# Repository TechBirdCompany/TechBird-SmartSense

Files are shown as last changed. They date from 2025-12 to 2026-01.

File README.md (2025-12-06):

# Introduction
TechBird-SmartSense is an IoT device with a 4-channel 12-Bit ADC, to measure up to 4 temperatures. In addition it also provides an internal temperature sensore for ambiant temperatures.

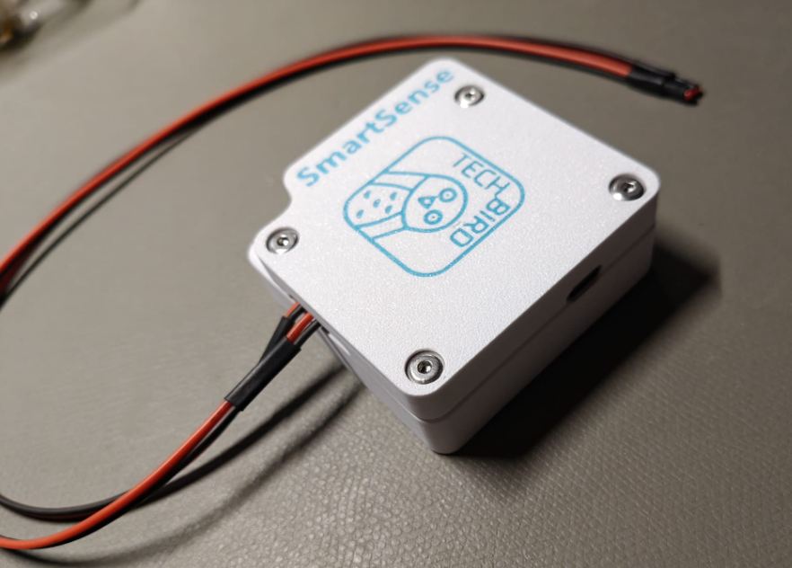
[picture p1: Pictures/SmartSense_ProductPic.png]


# Features
- ESP32-C6-MINI-1-N4: As module
- EEMB LP103454: 2000 mAh Lipo Battery
  - 7 days of uptime with 10 seconds time gab, and ringbuffer size of 60
- ADS1015IDGSR: 2 Differntiall or 4 Channel 12-Bit ADC
- FM24CL64B-GTR: 64 kB FRAM
- RV-3028-C7: Internal RTC
- TMP1075D: Internal Temperature Sensor
- USB Type-C for communication and charging
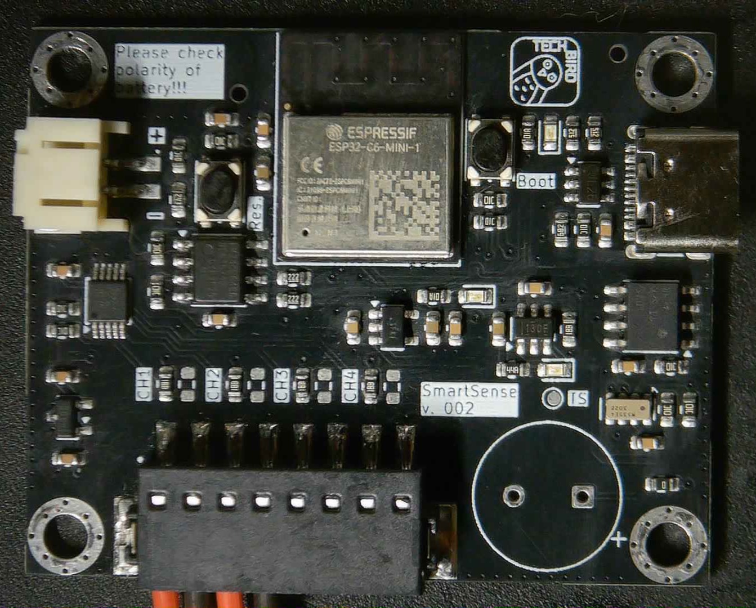
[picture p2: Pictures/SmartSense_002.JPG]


# Software
- Use at your own risk!
- Basic UI via USB (115200, 8, n, 1)
- Sending Data via MQTT
- Again... use at your own risk!
- Bugs are free to find, and free to fix.

# Known Bugs
## Hardware
- For some reasons, unknown to men, the LiPo Battery is necessary, to provide enough energy for initial W-LAN connection. Or maybe use a beefier USB power supply
- <span style="text-decoration:overline">WKUP</span> need to be routed to IO2
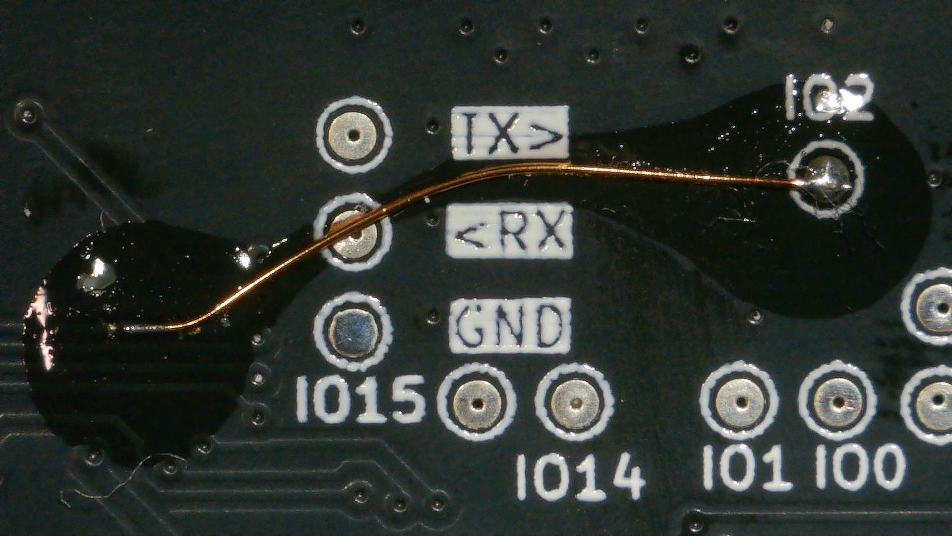
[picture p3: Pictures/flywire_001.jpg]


## Software
- When ringbuffer loops, one set of wrong data will be send

# Known Nuisances
- When in deep sleep, attaching USB connection won't reset the device and the lid need to be removed in order to get to the bootmenu
- Main connector is not made to be removed frequently, which makes charging pretty annoying

# Arduino IDE Setup
- The settings should look something like this:
  
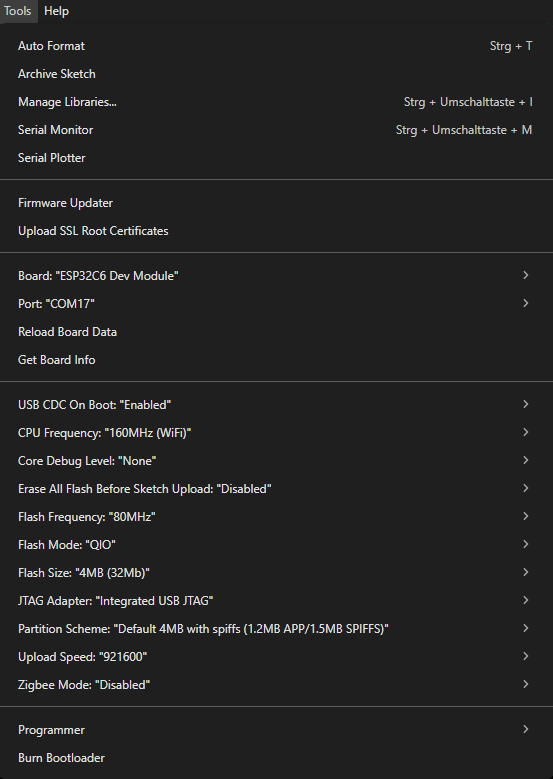
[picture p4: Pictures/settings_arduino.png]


- The following libraries shoulld be installed:
  - https://github.com/arduino-libraries/Arduino_JSON
  - https://github.com/arduino-libraries/NTPClient
  - https://github.com/adafruit/Adafruit_ADS1X15
  - https://github.com/hideakitai/DebugLog
  - https://github.com/RobTillaart/FRAM_I2C
  - https://github.com/256dpi/arduino-mqtt
  - https://github.com/constiko/RV-3028_C7-Arduino_Library
  - https://github.com/PatrickBaus/Arduino-TMP1075/tree/master
    - Needs to be installed manually

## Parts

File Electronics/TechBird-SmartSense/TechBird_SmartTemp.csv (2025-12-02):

Reference | Qty | Value | Tolerance | Footprint | MFG | MFG# | DigiKey | Distri Link
C1,C2,C3,C5,C7,C8,C10,C11,C12,C13,C14 | 11 | 100n |  | Capacitor_SMD:C_0603_1608Metric | KEMET | C0603C104K3RACTU | 399-C0603C104K3RACTUCT-ND | https://www.digikey.de/de/products/detail/kemet/C0603C104K3RACTU/416044
C4,C18 | 2 | 1u |  | Capacitor_SMD:C_0603_1608Metric | TDK Corporation | C1608X7R1C105K080DC | 445-C1608X7R1C105K080DCCT-ND | https://www.digikey.de/de/products/detail/tdk-corporation/C1608X7R1C105K080DC/22106152
C6,C9 | 2 | 10u |  | Capacitor_SMD:C_0603_1608Metric | Taiyo Yuden | LMK107BBJ106MALT | 587-3258-1-ND | https://www.digikey.de/de/products/detail/taiyo-yuden/LMK107BBJ106MALT/3662195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
C15 | 1 | 100m |  | Capacitor_THT:CP_Radial_Tantal_D10.5mm_P5.00mm | KEMET | FG0H104ZF | 399-10793-ND | https://www.digikey.de/de/products/detail/kemet/FG0H104ZF/4290859?s=N4IgTCBcDaIMwE4EFoCMAGA7AuyByAIiALoC%2BQA
D1,D2,D3 | 3 | LTST-C193TBKT-5A |  | LED_SMD:LED_0603_1608Metric | Lite-On Inc. | LTST-C193TBKT-5A | 160-1827-1-ND | https://www.digikey.de/de/products/detail/liteon/LTST-C193TBKT-5A/2053656
J1 | 1 | UJ20-C-H-G-SMT-P16-TR |  | Connector_USB:USB_C_Receptacle_G-Switch_GT-USB-7010ASV | Same Sky (Formerly CUI Devices) | UJ20-C-H-G-SMT-P16-TR | 2223-UJ20-C-H-G-SMT-P16-TRCT-ND | https://www.digikey.de/de/products/detail/same-sky-formerly-cui-devices-/UJ20-C-H-G-SMT-P16-TR/25588941
J2 | 1 | S2B-PH-SM4 |  | 000_Connector:JST_S2B-PH-SM4-TB | JST Sales America Inc. | S2B-PH-SM4-TB | 455-S2B-PH-SM4-TBCT-ND | https://www.digikey.de/de/products/detail/jst-sales-america-inc/S2B-PH-SM4-TB/926655
J3 | 1 | 1771088 |  | TB_Connectors:PHOENIX_1771088 | Phoenix Contact | 1771088 | 277-2071-1-ND | https://www.digikey.de/de/products/detail/phoenix-contact/1771088/2192452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
R1 | 1 | 280 |  | Resistor_SMD:R_0603_1608Metric | Panasonic Electronic Components | ERJ-3EKF2800V | P280HCT-ND | https://www.digikey.de/de/products/detail/panasonic-electronic-components/ERJ-3EKF2800V/196259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
R2,R6,R11,R12,R13,R14,R15,R16,R17,R18,R19,R21 | 12 | 10k |  | Resistor_SMD:R_0603_1608Metric | YAGEO | RC0603FR-0710KL | 311-10.0KHRCT-ND | https://www.digikey.de/de/products/detail/yageo/RC0603FR-0710KL/726880
R3,R5,R7,R23,R24 | 5 | 1.5k |  | Resistor_SMD:R_0603_1608Metric | Panasonic Electronic Components | ERA-3AEB152V | P1.5KDBCT-ND | https://www.digikey.de/de/products/detail/panasonic-electronic-components/ERA-3AEB152V/1465858
R4 | 1 | 24k |  | Resistor_SMD:R_0603_1608Metric | Vishay Dale | CRCW060324K0FKEAC | 541-5285-1-ND | https://www.digikey.de/de/products/detail/vishay-dale/CRCW060324K0FKEAC/7924008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
R8,R9 | 2 | 2.2k |  | Resistor_SMD:R_0603_1608Metric | TE Connectivity Passive Product | CRGCQ0603F2K2 | A129692CT-ND | https://www.digikey.de/de/products/detail/te-connectivity-passive-product/CRGCQ0603F2K2/8576294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
R10,R20 | 2 | 100 |  | Resistor_SMD:R_0603_1608Metric | Vishay Dale | CRCW0603100RFKEA | 541-100HCT-ND | https://www.digikey.de/de/products/detail/vishay-dale/CRCW0603100RFKEA/1174554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
R22 | 1 | 6.8k |  | Resistor_SMD:R_0603_1608Metric | Panasonic Electronic Components | ERJ-1GNF6801C | P123125CT-ND | https://www.digikey.de/de/products/detail/panasonic-electronic-components/ERJ-1GNF6801C/2036207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
R25,R26 | 2 | 5.1k |  | Resistor_SMD:R_0603_1608Metric | YAGEO | RC0603FR-075K1L | 311-5.10KHRCT-ND | https://www.digikey.de/de/products/detail/yageo/RC0603FR-075K1L/727268
R27 | 1 | 0 |  | Resistor_SMD:R_0603_1608Metric | Bourns Inc. | CR0603AJ/-000EAS | CR0603AJ/-000EASCT-ND | https://www.digikey.de/de/products/detail/bourns-inc/CR0603AJ-000EAS/10240122
SW1,SW2 | 2 | SKRPARE010 |  | Button_Switch_SMD:SW_Push_1P1T_NO_Vertical_Wuerth_434133025816 | Alps Alpine | SKRPARE010 | 4809-SKRPARE010CT-ND | https://www.digikey.de/de/products/detail/alps-alpine/skrpare010/26519642
U1 | 1 | USBLC6-2SC6 |  | Package_TO_SOT_SMD:SOT-23-6 | STMicroelectronics | USBLC6-2SC6 | 497-5235-1-ND | https://www.digikey.de/de/products/detail/stmicroelectronics/USBLC6-2SC6/1040559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
U2 | 1 | TMP1075D |  | Package_SO:SOIC-8_3.9x4.9mm_P1.27mm | Texas Instruments | TMP1075DR | 296-51833-1-ND | https://www.digikey.de/de/products/detail/texas-instruments/TMP1075DR/9685283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
U3 | 1 | BQ21040DBVR |  | Package_TO_SOT_SMD:SOT-23-6 | Texas Instruments | BQ21040DBVR | 296-47315-1-ND | https://www.digikey.de/de/products/detail/texas-instruments/BQ21040DBVR/6036340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
U4 | 1 | TLV75733PDBV |  | Package_TO_SOT_SMD:SOT-23-5 | Texas Instruments | TLV75733PDBVR | 296-50414-1-ND | https://www.digikey.de/de/products/detail/texas-instruments/TLV75733PDBVR/9343364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
U5 | 1 | REF3033 |  | Package_TO_SOT_SMD:SOT-23 | Texas Instruments | REF3033AIDBZR | 296-26324-1-ND
U6 | 1 | ESP32-C6-MINI-1-N4 |  | RF_Module:ESP32-C6-MINI-1 | Espressif Systems | ESP32-C6-MINI-1-N4 | 1965-ESP32-C6-MINI-1-N4CT-ND | https://www.digikey.de/de/products/detail/espressif-systems/ESP32-C6-MINI-1-N4/17885796
U7 | 1 | RV-3028-C7 |  | Package_SON:MicroCrystal_C7_SON-8_1.5x3.2mm_P0.9mm | Micro Crystal AG | RV-3028-C7 32.768KHZ 1PPM-TA-QA | 2195-RV-3028-C732.768KHZ1PPM-TA-QACT-ND | https://www.digikey.de/de/products/detail/micro-crystal-ag/RV-3028-C7-32-768KHZ-1PPM-TA-QA/10499248
U8 | 1 | FM24C64B-G |  | Package_SO:SOIC-8_3.9x4.9mm_P1.27mm | Infineon Technologies | FM24CL64B-GTR | 448-FM24CL64B-GTRCT-ND | https://www.digikey.de/de/products/detail/infineon-technologies/FM24CL64B-GTR/3788937
U9 | 1 | ADS1015IDGSR |  | Package_SO:TSSOP-10_3x3mm_P0.5mm | Texas Instruments | ADS1015IDGSR | 296-41185-1-ND | https://www.digikey.de/de/products/detail/texas-instruments/ADS1015IDGSR/2231559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

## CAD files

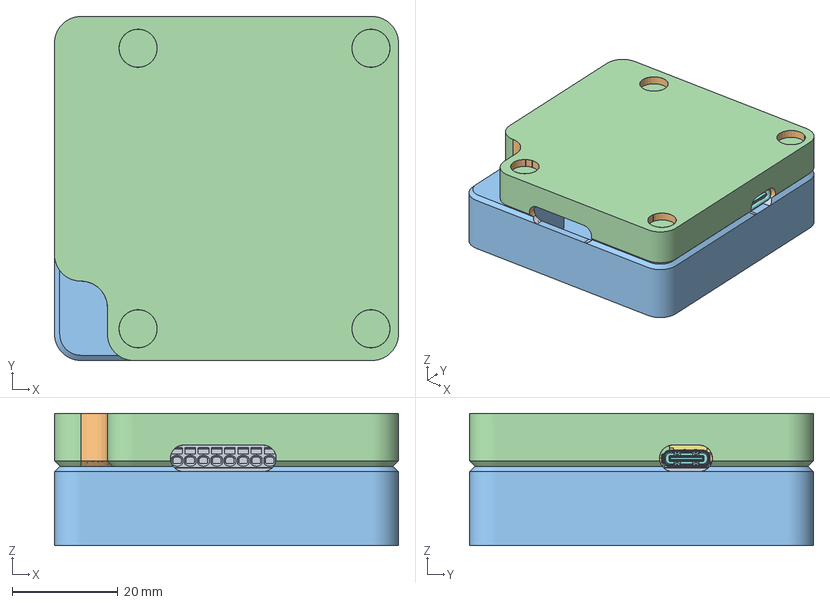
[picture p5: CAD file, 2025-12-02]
Mechanics/TechBird-SmartSense_Housing_001.FCStd
65.0 x 65.0 x 25.0 mm
SmartSense_Housing_Bottom
C_0603_1608Metric
R_0603_1608Metric
SOT-23-6
R_0603_1608Metric001
C_0603_1608Metric001
C_0603_1608Metric002
R_0603_1608Metric002
R_0603_1608Metric003
R_0603_1608Metric004
R_0603_1608Metric005
C_0603_1608Metric003
R_0603_1608Metric006
R_0603_1608Metric007
SOIC-8_3.9x4.9mm_P1.27mm
R_0603_1608Metric008
S2B-PH-SM4-TB
S2B-PH-SM4-TB001
S2B-PH-SM4-TB002
S2B-PH-SM4-TB003
S2B-PH-SM4-TB004
C_0603_1608Metric004
SOIC-8_3.9x4.9mm_P1.27mm001
R_0603_1608Metric009
R_0603_1608Metric010
R_0603_1608Metric011
SOT-23
R_0603_1608Metric012
R_0603_1608Metric013
R_0603_1608Metric014
R_0603_1608Metric015
R_0603_1608Metric016
C_0603_1608Metric005
R_0603_1608Metric017
R_0603_1608Metric018
SOT-23-5
R_0603_1608Metric019
LED_0603_1608Metric
C_0603_1608Metric006
C_0603_1608Metric007
C_0603_1608Metric008
R_0603_1608Metric020
R_0603_1608Metric021
C_0603_1608Metric009
LED_0603_1608Metric001
TSSOP-10_3x3mm_P0.5mm
C_0603_1608Metric010
R_0603_1608Metric022
C_0603_1608Metric011
R_0603_1608Metric023
C_0603_1608Metric012
C_0603_1608Metric013
UJ20-C-H-G-SMT-P16-TR
R_0603_1608Metric024
C_0603_1608Metric014
R_0603_1608Metric025
R_0603_1608Metric026
R_0603_1608Metric027
R_0603_1608Metric028
R_0603_1608Metric029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

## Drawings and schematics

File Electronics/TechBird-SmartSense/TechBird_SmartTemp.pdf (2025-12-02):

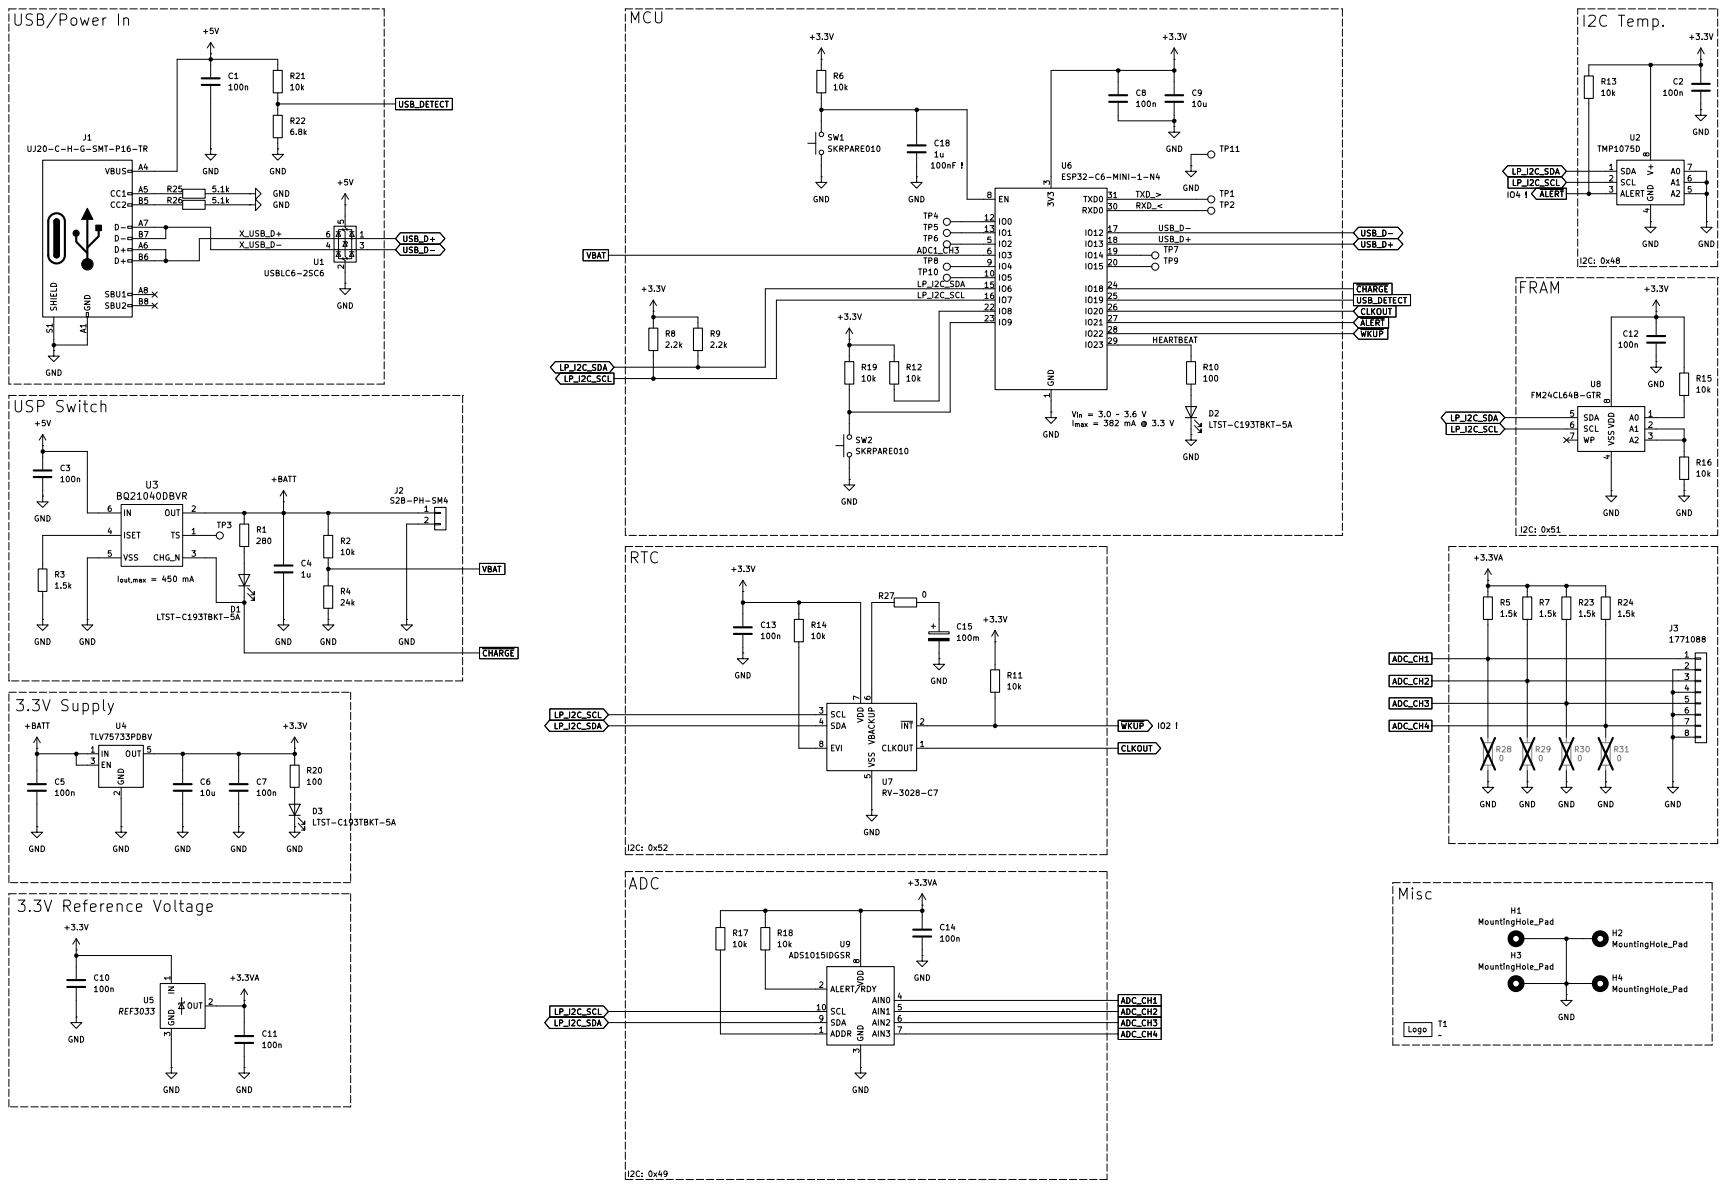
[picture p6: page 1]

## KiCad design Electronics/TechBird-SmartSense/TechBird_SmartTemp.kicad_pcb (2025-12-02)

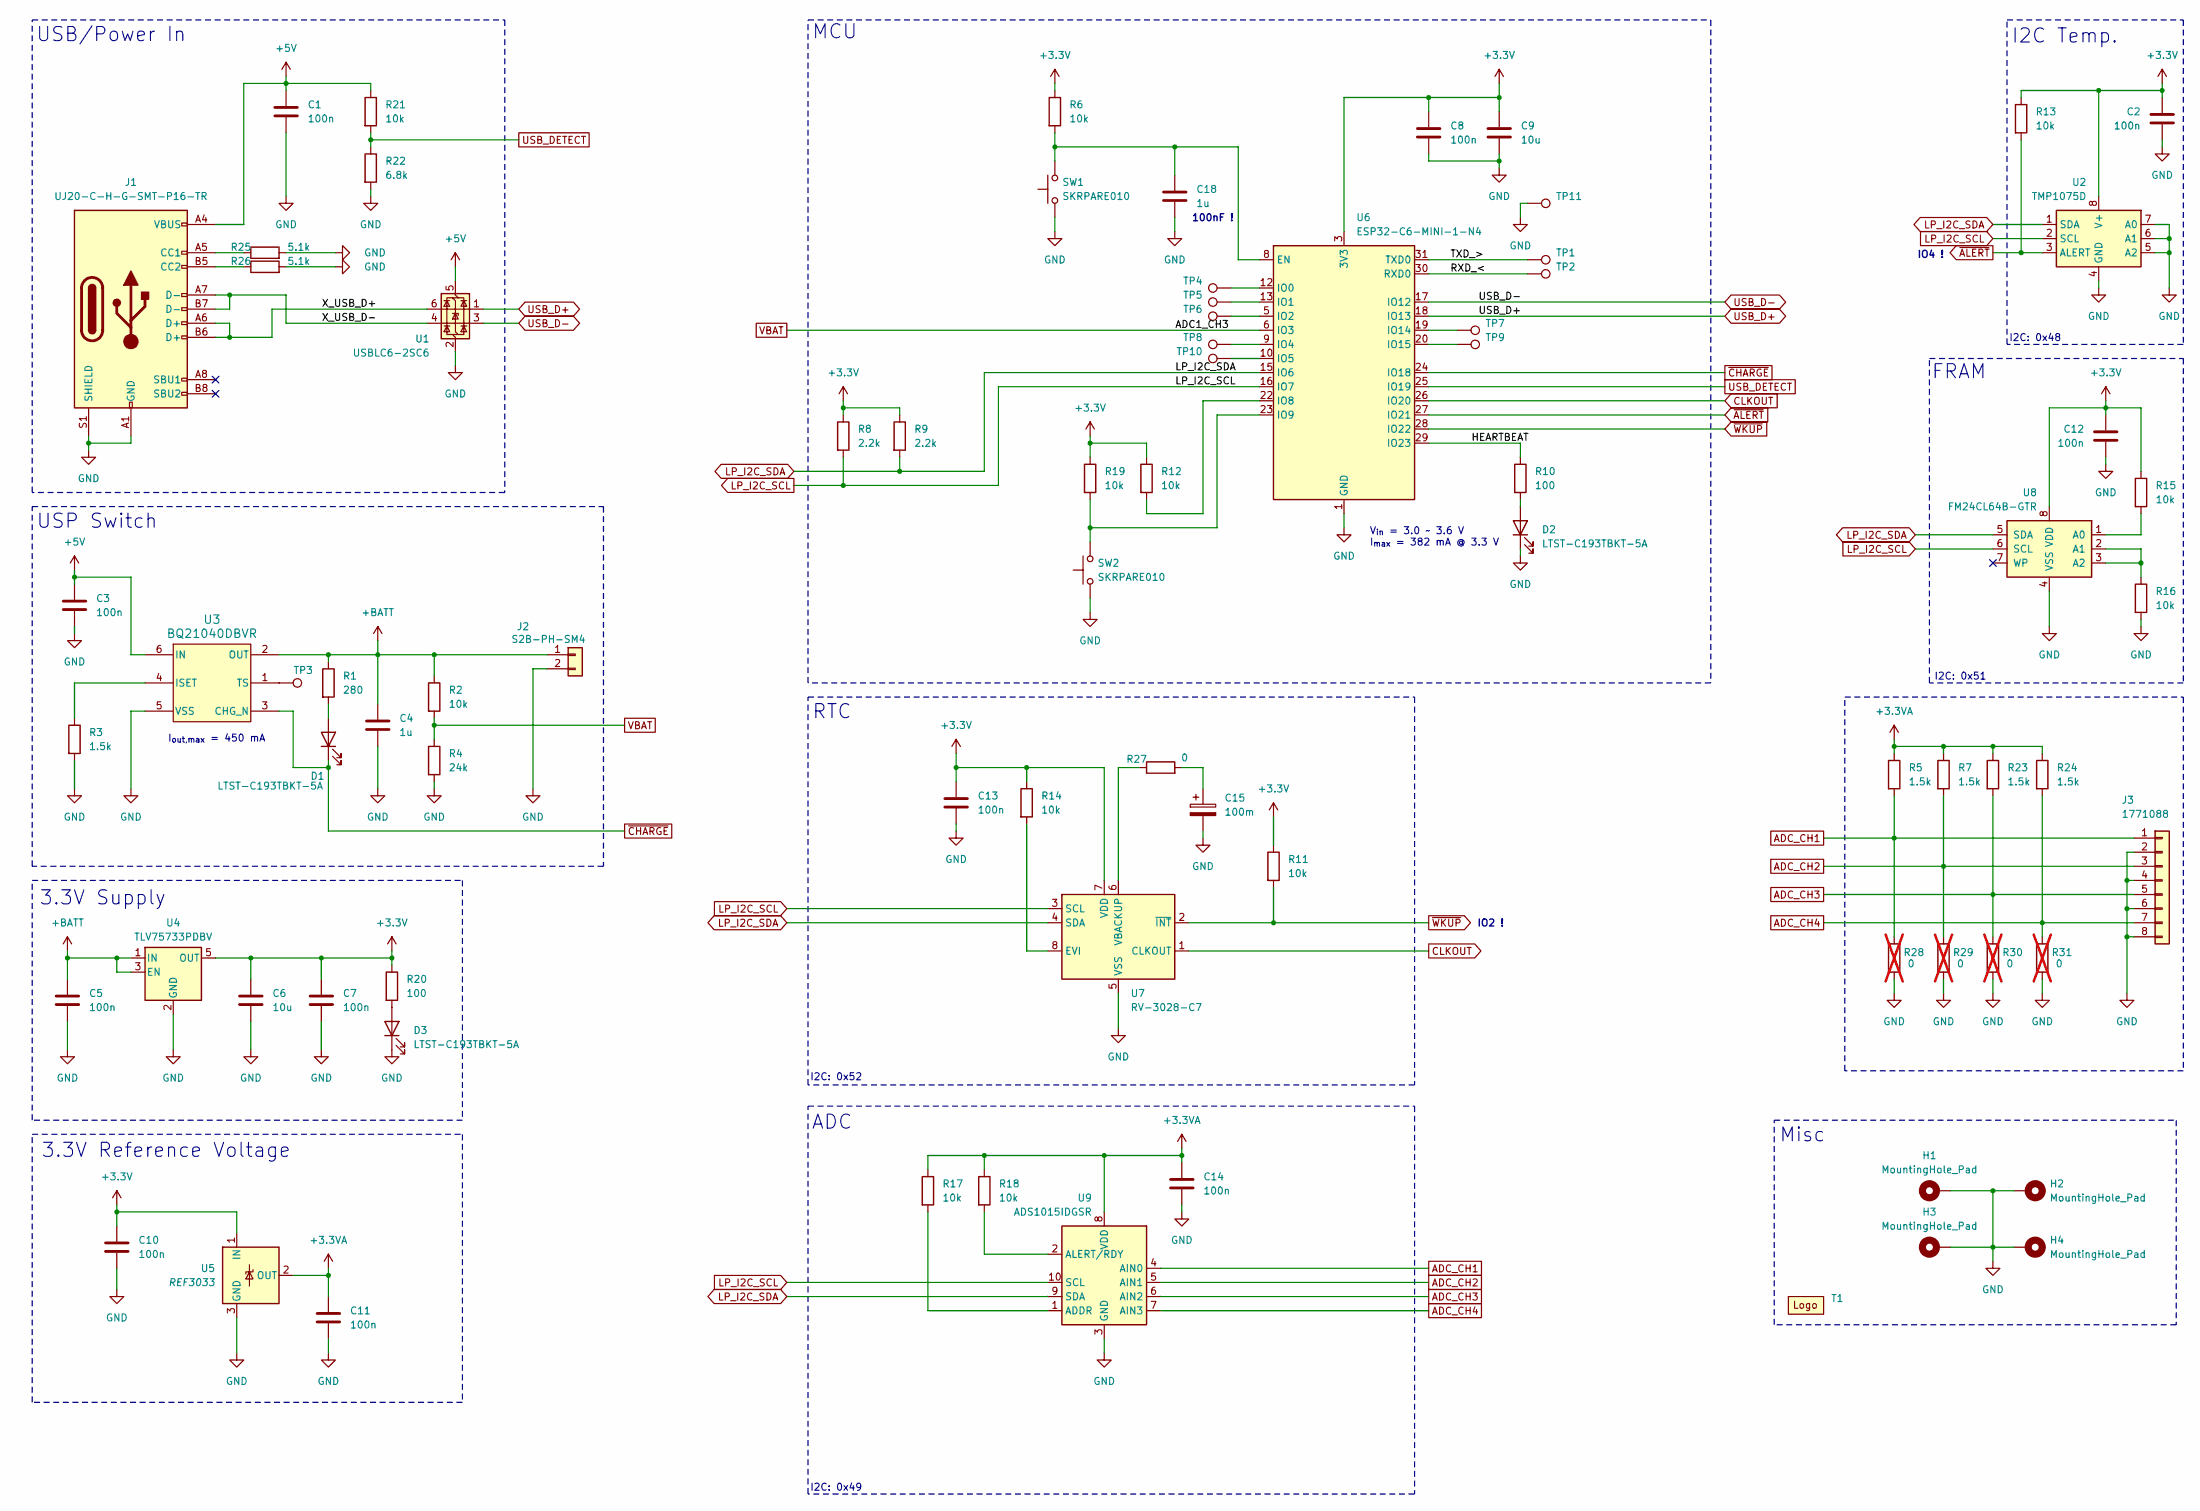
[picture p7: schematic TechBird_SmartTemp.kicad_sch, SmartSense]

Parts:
C1, C2, C3, C5, C7, C8, C10, C11, C12, C13, C14: 100n; C_0603_1608Metric; MFG# C0603C104K3RACTU; DigiKey 399-C0603C104K3RACTUCT-ND
C4, C18: 1u; C_0603_1608Metric; MFG# C1608X7R1C105K080DC; DigiKey 445-C1608X7R1C105K080DCCT-ND
C6, C9: 10u; C_0603_1608Metric; MFG# LMK107BBJ106MALT; DigiKey 587-3258-1-ND
C15: 100m; CP_Radial_Tantal_D10.5mm_P5.00mm; MFG# FG0H104ZF; DigiKey 399-10793-ND
D1, D2, D3: LTST-C193TBKT-5A; LED_0603_1608Metric; MFG# LTST-C193TBKT-5A; DigiKey 160-1827-1-ND
H1, H2, H3, H4: MountingHole_Pad; MountingHole_3.2mm_M3_DIN965_Pad
J1: UJ20-C-H-G-SMT-P16-TR; USB_C_Receptacle_G-Switch_GT-USB-7010ASV; MFG# UJ20-C-H-G-SMT-P16-TR; DigiKey 2223-UJ20-C-H-G-SMT-P16-TRCT-ND
J2: S2B-PH-SM4; JST_S2B-PH-SM4-TB; MFG# S2B-PH-SM4-TB; DigiKey 455-S2B-PH-SM4-TBCT-ND
J3: 1771088; PHOENIX_1771088; MFG# 1771088; DigiKey 277-2071-1-ND
R1: 280; R_0603_1608Metric; MFG# ERJ-3EKF2800V; DigiKey P280HCT-ND
R2, R6, R11, R12, R13, R14, R15, R16, R17, R18, R19, R21: 10k; R_0603_1608Metric; MFG# RC0603FR-0710KL; DigiKey 311-10.0KHRCT-ND
R3, R5, R7, R23, R24: 1.5k; R_0603_1608Metric; MFG# ERA-3AEB152V; DigiKey P1.5KDBCT-ND
R4: 24k; R_0603_1608Metric; MFG# CRCW060324K0FKEAC; DigiKey 541-5285-1-ND
R8, R9: 2.2k; R_0603_1608Metric; MFG# CRGCQ0603F2K2; DigiKey A129692CT-ND
R10, R20: 100; R_0603_1608Metric; MFG# CRCW0603100RFKEA; DigiKey 541-100HCT-ND
R22: 6.8k; R_0603_1608Metric; MFG# ERJ-1GNF6801C; DigiKey P123125CT-ND
R25, R26: 5.1k; R_0603_1608Metric; MFG# RC0603FR-075K1L; DigiKey 311-5.10KHRCT-ND
R27: 0; R_0603_1608Metric; MFG# CR0603AJ/-000EAS; DigiKey CR0603AJ/-000EASCT-ND
R28, R29, R30, R31: 0; R_0603_1608Metric; MFG# CR0603AJ/-000EAS; DigiKey CR0603AJ/-000EASCT-ND; not fitted
SW1, SW2: SKRPARE010; SW_Push_1P1T_NO_Vertical_Wuerth_434133025816; MFG# SKRPARE010; DigiKey 4809-SKRPARE010CT-ND
T1: TechBird_Silk
TP1, TP2, TP3, TP4, TP5, TP6, TP7, TP8, TP9, TP10, TP11: TestPoint; TestPoint_Pad_D1.0mm
U1: USBLC6-2SC6; SOT-23-6; MFG# USBLC6-2SC6; DigiKey 497-5235-1-ND
U2: TMP1075D; SOIC-8_3.9x4.9mm_P1.27mm; MFG# TMP1075DR; DigiKey 296-51833-1-ND
U3: BQ21040DBVR; SOT-23-6; MFG# BQ21040DBVR; DigiKey 296-47315-1-ND
U4: TLV75733PDBV; SOT-23-5; MFG# TLV75733PDBVR; DigiKey 296-50414-1-ND
U5: REF3033; SOT-23; MFG# REF3033AIDBZR; DigiKey 296-26324-1-ND
U6: ESP32-C6-MINI-1-N4; ESP32-C6-MINI-1; MFG# ESP32-C6-MINI-1-N4; DigiKey 1965-ESP32-C6-MINI-1-N4CT-ND
U7: RV-3028-C7; MicroCrystal_C7_SON-8_1.5x3.2mm_P0.9mm; MFG# RV-3028-C7 32.768KHZ 1PPM-TA-QA; DigiKey 2195-RV-3028-C732.768KHZ1PPM-TA-QACT-ND
U8: FM24CL64B-GTR; SOIC-8_3.9x4.9mm_P1.27mm; MFG# FM24CL64B-GTR; DigiKey 448-FM24CL64B-GTRCT-ND
U9: ADS1015IDGSR; TSSOP-10_3x3mm_P0.5mm; MFG# ADS1015IDGSR; DigiKey 296-41185-1-ND

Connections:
+3.3V: C2.1, C6.1, C7.1, C8.1, C9.1, C10.1, C12.1, C13.1, R6.1, R8.1, R9.1, R11.1, R12.1, R13.1, R14.1, R15.1, R19.1, R20.1, U2.8 (V+), U4.5 (OUT), U5.1 (IN), U6.3 (3V3), U7.7 (VDD), U8.8 (VDD)
+3.3VA: C11.1, C14.1, R5.1, R7.1, R17.1, R18.1, R23.1, R24.1, U5.2 (OUT), U9.8 (VDD)
+5V: C1.1, C3.1, J1.A4 (VBUS), J1.A9 (VBUS), J1.B4 (VBUS), J1.B9 (VBUS), R21.1, U1.5 (VBUS), U3.6 (IN)
+BATT: C4.1, C5.1, J2.1, R1.1, R2.1, U3.2 (OUT), U4.1 (IN), U4.3 (EN)
/HEARTBEAT: R10.1, U6.29 (IO23)
/RXD_<: TP2.1, U6.30 (RXD0)
/TXD_>: TP1.1, U6.31 (TXD0)
/X_USB_D+: J1.A6 (D+), J1.B6 (D+), U1.6 (I/O1)
/X_USB_D-: J1.A7 (D-), J1.B7 (D-), U1.4 (I/O2)
ADC_CH1: J3.1, R5.2, R28.2, U9.4 (AIN0)
ADC_CH2: J3.3, R7.2, R29.2, U9.5 (AIN1)
ADC_CH3: J3.5, R23.2, R30.2, U9.6 (AIN2)
ADC_CH4: J3.7, R24.2, R31.2, U9.7 (AIN3)
CLKOUT: U6.26 (IO20), U7.1 (CLKOUT)
GND: C1.2, C2.2, C3.2, C4.2, C5.2, C6.2, C7.2, C8.2, C9.2, C10.2, C11.2, C12.2, C13.2, C14.2, C15.2, C18.2, D2.1 (K), D3.1 (K), H1.1, H2.1, H3.1, H4.1, J1.A1 (GND), J1.A12 (GND), J1.B1 (GND), J1.B12 (GND), J1.S1 (SHIELD), J2.2, J3.2, J3.4, J3.6, J3.8, R3.2, R4.2, R16.2, R22.2, R25.2, R26.2, R28.1, R29.1, R30.1, R31.1, SW1.1, SW2.1, TP11.1, U1.2 (GND), U2.4 (GND), U2.5 (A2), U2.6 (A1), U2.7 (A0), U3.5 (VSS), U4.2 (GND), U5.3 (GND), U6.1 (GND), U6.2 (GND), U6.11 (GND), U6.14 (GND), U6.36 (GND), U6.37 (GND), U6.38 (GND), U6.39 (GND), U6.40 (GND), U6.41 (GND), U6.42 (GND), U6.43 (GND), U6.44 (GND), U6.45 (GND), U6.46 (GND), U6.47 (GND), U6.48 (GND), U6.49 (GND), U6.50 (GND), U6.51 (GND), U6.52 (GND), U6.53 (GND), U7.5 (VSS), U8.4 (VSS), U9.3 (GND)
LP_I2C_SCL: R8.2, U2.2 (SCL), U6.16 (IO7), U7.3 (SCL), U8.6 (SCL), U9.10 (SCL)
LP_I2C_SDA: R9.2, U2.1 (SDA), U6.15 (IO6), U7.4 (SDA), U8.5 (SDA), U9.9 (SDA)
unnamed: C15.1, R27.2
unnamed: D1.2 (A), R1.2
unnamed: D2.2 (A), R10.2
unnamed: D3.2 (A), R20.2
unnamed: J1.A5 (CC1), R25.1
unnamed: J1.B5 (CC2), R26.1
unnamed: R3.1, U3.4 (ISET)
unnamed: TP3.1, U3.1 (TS)
unnamed: C18.1, R6.2, SW1.2, U6.8 (EN)
unnamed: TP4.1, U6.12 (IO0)
unnamed: TP5.1, U6.13 (IO1)
unnamed: TP6.1, U6.5 (IO2)
unnamed: TP8.1, U6.9 (IO4)
unnamed: TP10.1, U6.10 (IO5)
unnamed: R12.2, U6.22 (IO8)
unnamed: R19.2, SW2.2, U6.23 (IO9)
unnamed: TP7.1, U6.19 (IO14)
unnamed: TP9.1, U6.20 (IO15)
unnamed: R14.2, U7.8 (EVI)
unnamed: R27.1, U7.6 (VBACKUP)
unnamed: R15.2, U8.1 (A0)
unnamed: R16.1, U8.2 (A1), U8.3 (A2)
unnamed: R17.2, U9.1 (ADDR)
unnamed: R18.2, U9.2 (ALERT/RDY)
USB_D+: U1.1 (I/O1), U6.18 (IO13)
USB_D-: U1.3 (I/O2), U6.17 (IO12)
USB_DETECT: R21.2, R22.1, U6.25 (IO19)
VBAT: R2.2, R4.1, U6.6 (IO3)
~ALERT: R13.2, U2.3 (ALERT), U6.27 (IO21)
~CHARGE: D1.1 (K), U3.3 (CHG_N), U6.24 (IO18)
~WKUP: R11.2, U6.28 (IO22), U7.2 (~INT)

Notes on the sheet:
3.3V Reference Voltage
3.3V Supply
USP Switch
Misc
I2C Temp.
USB/Power In
I2C: 0x49
V_{in} = 3.0 ~ 3.6 V I_{max} = 382 mA @ 3.3 V
I2C: 0x52
RTC
I_{out,max} = 450 mA
I2C: 0x51
ADC
100nF !
IO4 !
IO2 !
MCU
I2C: 0x48
FRAM

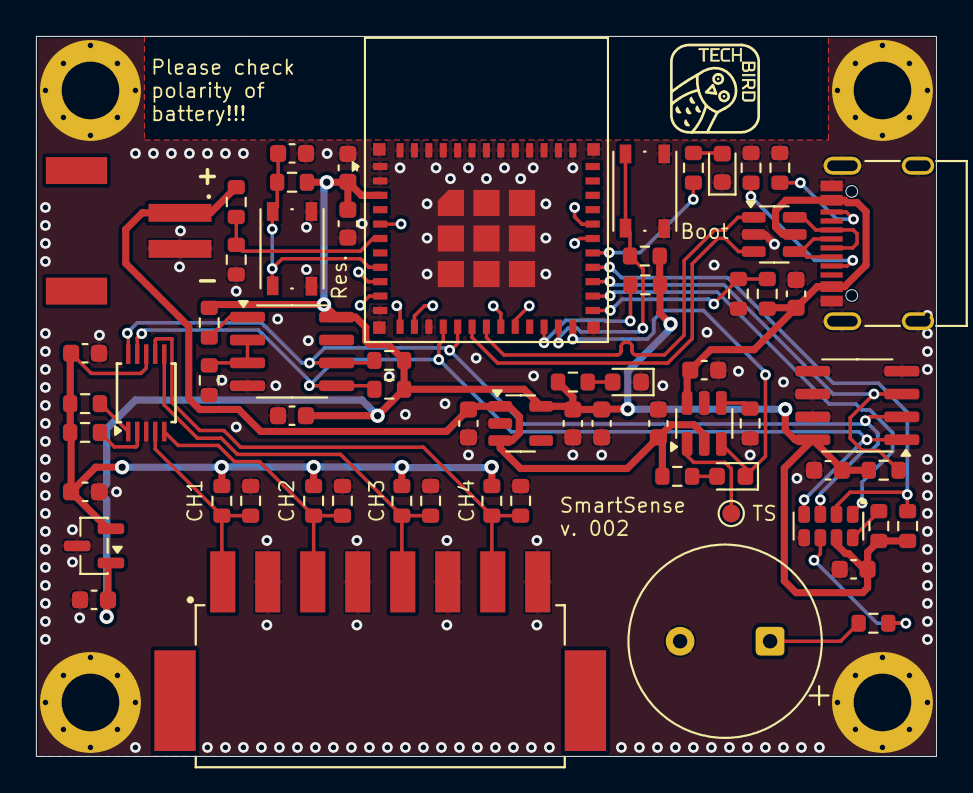
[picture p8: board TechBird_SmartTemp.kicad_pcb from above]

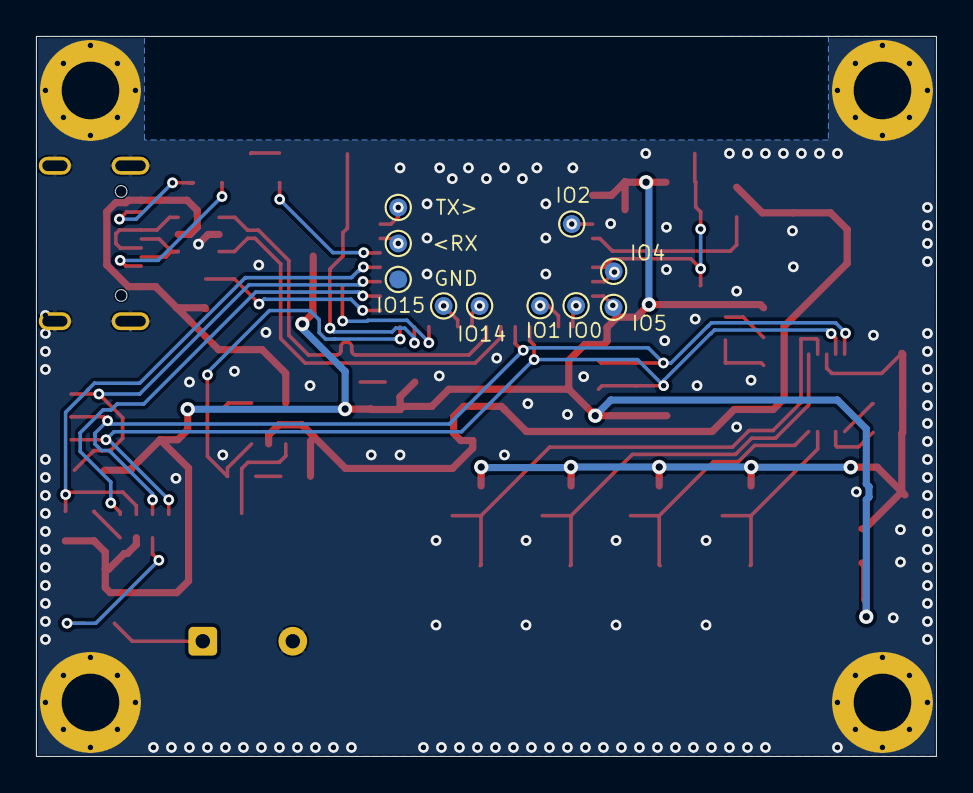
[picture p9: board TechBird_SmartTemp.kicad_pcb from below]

Board: 2 copper layers, 50.0 x 40.0 mm, 80 parts (10 on the bottom side), 48 nets.

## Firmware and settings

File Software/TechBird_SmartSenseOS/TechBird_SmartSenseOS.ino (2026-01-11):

//---------------------------------------------
// Includes
//---------------------------------------------
#include <WiFi.h>
#include <Preferences.h>
#include <DebugLog.h>
#include <TMP1075.h>
#include <Wire.h>
#include <Adafruit_ADS1X15.h>
#include <NTPClient.h>
#include <MQTT.h>
#include <RV-3028-C7.h>
#include <esp_system.h>
#include <math.h>
#include <FRAM.h>
#include <ArduinoJson.h>
#include <esp_bt.h>
#include <driver/adc.h>
#include <esp_sleep.h>
#include <driver/usb_serial_jtag.h>
#include <driver/rtc_io.h>
//---------------------------------------------



//---------------------------------------------
// Defines GIOS
//---------------------------------------------
#define HEARTBEAT_LED 23
#define VBAT_ADC 3
#define nWKUP 2
#define USB_DETECT 19
//---------------------------------------------



//---------------------------------------------
// Preamble WLAN
//---------------------------------------------
WiFiClient net;
void printWiFiStatus();
//---------------------------------------------



//---------------------------------------------
// Preamble I2C
//---------------------------------------------
#define I2C_SDA 6
#define I2C_SCL 7
#define I2C_ADC_ADDRESS 0x49
#define I2C_FRAM_ADDRESS 0x51
#define I2C_TEMP_ADDRESS 0x48
//---------------------------------------------



//---------------------------------------------
// Preamble MQTT
//---------------------------------------------
MQTTClient mqttClient;

struct mqtt_struct {
  uint8_t index;
  bool status;
  unsigned long timestamp;
  uint16_t voltage_battery;
  float internal_temperature;
  float internal_offset;
  float ext_ch[4];
  float ext_offset[4];
} mqtt_data;

enum mqtt_struct_status {
  READY_TO_WRITE,
  READY_TO_SEND,
  READY_TO_DELETE
};

void initMQTT();
//---------------------------------------------



//---------------------------------------------
// Preamble RTC
//---------------------------------------------
RV3028 rtc;

void updateRTCFromNTP();
unsigned long getRTCEpoch();
String getRTC_ISO8601();
bool setInterrupt(uint32_t newTimeSeconds, bool repeat = true);
//---------------------------------------------



//---------------------------------------------
// Preamble NTP
//---------------------------------------------
WiFiUDP ntpUDP;
time_t timegm_esp32(struct tm *tm);
NTPClient timeClient(ntpUDP, "europe.pool.ntp.org");
//---------------------------------------------



//---------------------------------------------
// Preamble TMP1075
//---------------------------------------------
TMP1075::TMP1075 tmp1075 = TMP1075::TMP1075(Wire, I2C_TEMP_ADDRESS);

float tmp_read_temperature(TMP1075::ConversionTime time);
//---------------------------------------------



//---------------------------------------------
// Preamble ADS1x15
//---------------------------------------------
#define ADC_GAIN GAIN_TWOTHIRDS  //GAIN_TWO  //GAIN_EIGHT

Adafruit_ADS1015 ads;

float tmp_read_ext_temperature[4];
float calcNTCTemperature(int channel);
float lastValidTemp[4] = { NAN, NAN, NAN, NAN };
float filteredNTC(int channel);
//---------------------------------------------



//---------------------------------------------
// Preamble Bootmenu
//---------------------------------------------
enum InputMode {
  SINGLE_CHAR,
  LINE_INPUT
};
bool bootmenuActive = false;
unsigned long bootTimer;

void runBootmenu();
void bootmenu_Main();
void bootmenu_WLAN_Submenu();
void bootmenu_MQTT_Submenu();
void bootmenu_Temp_Internal_Submenu();
void bootmenu_Temp_External_Submenu();
String readSerialLine();
String maskPassword(const String &pw);
void clearScreen();
//---------------------------------------------



//---------------------------------------------
// Preamble NVS
//--------------------------------------------
Preferences prefs;

struct struct_system_config {
  String wifi_ssid;
  String wifi_pass;
  String mqtt_server_ip;
  int mqtt_server_port;
  String mqtt_id;
  String mqtt_user;
  String mqtt_user_pass;
  String mqtt_topic;
  int interval;
  float internal_offset;
  float ext_offset_ch[4];
  float ext_rs_ch[4];
  float ext_rn_ch[4];
  float ext_tn_ch[4];
  float ext_b_ch[4];
  int sps;
  bool debug_led = false;
  bool deep_sleep = true;
  float ref_volt;
  bool send_singles = false;
} system_config;

void saveConfig(struct_system_config &config);
void loadConfig(struct_system_config &config);
//---------------------------------------------



//---------------------------------------------
// Preamble ESP
//---------------------------------------------
volatile bool uploadRunning = false;
volatile bool samplingActive = false;

uint16_t uploadStartIndex = 0;
uint16_t uploadEndIndex = 0;
float lastValidBattery = NAN;

float adc_read_voltage();
void scanI2CBus();
void manageData();

void uploadTask(void *param);
void samplingTask(void *param);
void runBootmenu();
float filteredBattery();
bool deepSleepPossible();
void setupConnect();
//---------------------------------------------



//---------------------------------------------
// Preamble Error Code
//---------------------------------------------
enum LedMode {
  LED_OFF,
  LED_HEARTBEAT,
  LED_UPLOAD,
  LED_ERROR,
  LED_SAMPLING
};

enum ErrorCode {
  ERROR_NONE,
  ERROR_MQTT,
  ERROR_WIFI,
  ERROR_GENERAL,
  ERROR_ADC,
  ERROR_I2C,
  ERROR_FRAM,
  ERROR_RTC,
  ERROR_SEND
};

volatile LedMode currentLedMode = LED_OFF;
volatile ErrorCode currentError = ERROR_NONE;

const int SHORT_DELAY = 300;
const int LONG_DELAY = 700;
const int CYCLE_DELAY = 2000;
void crashHandler();
void ledTask(void *param);
//---------------------------------------------



//---------------------------------------------
// Preamble FRAM
//---------------------------------------------
FRAM fram;
const uint16_t FRAM_ADDR_START = 0;
const size_t STRUCT_SIZE = sizeof(mqtt_struct);
const uint16_t MAX_RECORDS = 2048;

struct FramHeader {
  uint32_t magic;
  uint32_t writeIndex;
  uint32_t readIndex;
};

const uint32_t FRAM_MAGIC = 0xA3F71C2B;
const uint16_t FRAM_HEADER_ADDR = 0;

FramHeader header;


void writeMQTTToFRAM(uint16_t addr, const mqtt_struct &data);
void readMQTTFromFRAM(uint16_t addr, mqtt_struct &data);
void loadFramHeader();
void saveFramHeader();
//---------------------------------------------



//================================================================================
// Setup
//================================================================================
void setup() {

  unsigned long startWait = millis();

  // Try to save power
  setCpuFrequencyMhz(80);
  btStop();

  // Initilize GPIOs
  pinMode(nWKUP, INPUT);
  pinMode(USB_DETECT, INPUT);

  // Initilize LED
  statusLedInit();

  // Switch Serial depending on an attached USB device
  if (usb_serial_jtag_is_connected()) {

    Serial.begin(115200);
    while (!Serial && millis() - startWait < 1000 * 5) {
      // Just wait
    }
    LOG_INFO("USB interface active\r");
    Serial.println("\nGreetings Professor Falken.\n");
  } else {
    LOG_SET_LEVEL(DebugLogLevel::LVL_NONE);
  }

  // Load NVS
  loadConfig(system_config);

  // Initilize I2C
  LOG_INFO("Initilize I2C\r");
  Wire.setClock(400000);
  if (!Wire.begin(I2C_SDA, I2C_SCL)) {
    setErrorCode(ERROR_I2C);
    crashHandler();
  }

  // Initilize FRAM
  LOG_INFO("Initilize FRAM\r");
  if (fram.begin(I2C_FRAM_ADDRESS) != 0) {
    LOG_ERROR("Initilize FRAM failed!\r");
    setErrorCode(ERROR_FRAM);
    crashHandler();
  } else {
    loadFramHeader();
  }

  // Initilize Connection
  if (system_config.send_singles) {
    setupConnect();
  }

  // Initilize TMP1075
  LOG_INFO("Initilize TMP1075\r");
  tmp1075.begin();

  // Initilize ADS1x15
  LOG_INFO("Initilize ADS1x15\r");
  if (!ads.begin(I2C_ADC_ADDRESS)) {
    LOG_ERROR("Initilize ADS1x15 failed!\r");
    setErrorCode(ERROR_ADC);
    crashHandler();
  } else {
    ads.setGain(ADC_GAIN);
  }

  // Initilize RTC
  if (!rtc.begin()) {
    LOG_ERROR("Initilize RV-3028-C7 failed!");
    setErrorCode(ERROR_RTC);
    crashHandler();
  } else {
    setInterrupt(system_config.sps, true);
    rtc.set24Hour();
  }

  esp_reset_reason_t resetReason = esp_reset_reason();

  esp_sleep_wakeup_cause_t wakeBefore = esp_sleep_get_wakeup_cause();
  bool wokeFromDeepSleep = (wakeBefore != ESP_SLEEP_WAKEUP_UNDEFINED);

  esp_sleep_disable_wakeup_source(ESP_SLEEP_WAKEUP_ALL);

  esp_sleep_wakeup_cause_t wakeAfter = esp_sleep_get_wakeup_cause();

  LOG_INFO("Reset reason: ", resetReason, "\r");
  LOG_INFO("Wake BEFORE clear: ", wakeBefore, "\r");
  LOG_INFO("Wake AFTER clear: ", wakeAfter, "\r");
  LOG_INFO("DeepSleep wake flag: ", wokeFromDeepSleep, "\r");

  if (!wokeFromDeepSleep && (resetReason == ESP_RST_POWERON || resetReason == ESP_RST_EXT)) {
    runBootmenu();
  } else if (wokeFromDeepSleep) {
    LOG_INFO("DeepSleep wakeup — Bootmenu skipped.\r");
  } else if (resetReason == ESP_RST_SW) {
    LOG_INFO("Software reset — Bootmenu skipped.\r");
  }

  pinMode(nWKUP, INPUT);
  rtc_gpio_pullup_dis((gpio_num_t)nWKUP);
  rtc_gpio_pulldown_dis((gpio_num_t)nWKUP);
  esp_deep_sleep_enable_gpio_wakeup(1ULL << nWKUP, ESP_GPIO_WAKEUP_GPIO_LOW);

  LOG_INFO("Setup finished\r");
  xTaskCreatePinnedToCore(samplingTask, "Sampler", 4096, &system_config.sps, 1, NULL, 0);

  if (!system_config.send_singles) {
    xTaskCreatePinnedToCore(uploadTask, "Uploader", 8192, &system_config.interval, 1, NULL, 0);
  }

  xTaskCreatePinnedToCore(ledTask, "LED_Task", 2048, NULL, 2, NULL, 0);

  if (usb_serial_jtag_is_connected()) {
    xTaskCreatePinnedToCore(bootmenuTask, "Bootmenu", 2048, NULL, 2, NULL, 0);
  }
}
//================================================================================



//================================================================================
// Main loop
//================================================================================
void loop() {
}
//================================================================================



//---------------------------------------------
// ESP
//---------------------------------------------
void setupConnect() {
  WiFi.persistent(false);
  WiFi.mode(WIFI_STA);
  WiFi.begin(system_config.wifi_ssid, system_config.wifi_pass);
  unsigned long wifiStart = millis();
  while (WiFi.status() != WL_CONNECTED && millis() - wifiStart < 8000) {
    vTaskDelay(pdMS_TO_TICKS(100));
  }

  if (WiFi.status() != WL_CONNECTED) {
    LOG_ERROR("WiFi connection failed\r");
    setErrorCode(ERROR_WIFI);
    uploadRunning = false;
  } else {
    LOG_INFO("WiFi connected\r");
  }

  LOG_INFO("Initilize NTP\r");

  updateRTCFromNTP();

  initMQTT();
  unsigned long mqttStart = millis();
  while (!mqttClient.connected() && millis() - mqttStart < 5000) {
    mqttClient.loop();
    vTaskDelay(pdMS_TO_TICKS(50));
  }

  if (!mqttClient.connected()) {
    LOG_ERROR("MQTT connection failed\r");
    setErrorCode(ERROR_MQTT);
    //uploadRunning = false;
  }
}

bool deepSleepPossible() {
  if (system_config.interval * system_config.sps < 10 && !system_config.send_singles) {
    LOG_WARN("Deep Sleep not possible... time for sleep must be > 10 Seconds\r");
    return false;
  } else if (system_config.sps < 10 && system_config.send_singles) {
    LOG_WARN("Deep Sleep not possible... time for sleep must be > 10 Seconds\r");
    return false;
  } else {
    return true;
  }
}

void samplingTask(void *param) {
  unsigned long sps_s = *(unsigned long *)param;

  while (bootmenuActive) {
    vTaskDelay(pdMS_TO_TICKS(200));
  }

  setLedMode(LED_SAMPLING);

  while (1) {
    mqtt_struct data;
    data.index = header.writeIndex;
    data.status = true;
    data.timestamp = rtc.getUNIX();
    data.voltage_battery = filteredBattery();
    data.internal_temperature = tmp_read_temperature(TMP1075::ConversionTime220ms);
    data.internal_offset = system_config.internal_offset;
    for (int i = 0; i < 4; i++) {
      data.ext_ch[i] = filteredNTC(i);
      data.ext_offset[i] = system_config.ext_offset_ch[i];
    }

    String logMsg = "Saved dataset #" + String(data.index) + " | Timestamp: " + String(data.timestamp) + " | Bat: " + String(data.voltage_battery / 1000.0, 2) + " V" + " | IntTemp: " + String(data.internal_temperature, 2) + " °C" + " | Offset: " + String(data.internal_offset, 2) + " °C";
    for (int i = 0; i < 4; i++) {
      logMsg += " | CH" + String(i + 1) + ": " + String(data.ext_ch[i], 2) + " °C (Offset: " + String(data.ext_offset[i], 2) + ")";
    }
    LOG_INFO(logMsg.c_str(), "\r");

    if (system_config.send_singles) {
      setupConnect();
      publishMqttData(system_config.mqtt_topic.c_str(), data);
      unsigned long t0 = millis();
      while (millis() - t0 < 500) {
        mqttClient.loop();
        vTaskDelay(pdMS_TO_TICKS(10));
      }
      uploadRunning = false;
    } else {
      uint16_t addr = FRAM_ADDR_START + header.writeIndex * STRUCT_SIZE;
      writeMQTTToFRAM(addr, data);

      header.writeIndex = (header.writeIndex + 1) % MAX_RECORDS;
      saveFramHeader();

      uint16_t count = (header.writeIndex >= header.readIndex) ? (header.writeIndex - header.readIndex) : (MAX_RECORDS - header.readIndex + header.writeIndex);

      if (count >= system_config.interval && !uploadRunning) {
        uploadRunning = true;
      }
    }

    if (!uploadRunning && !bootmenuActive && system_config.deep_sleep && deepSleepPossible()) {
      WiFi.disconnect(true);
      WiFi.mode(WIFI_OFF);
      mqttClient.disconnect();

      LOG_INFO("Entering Deep Sleep until RTC pulse...\r");

      pinMode(nWKUP, INPUT);
      rtc_gpio_pullup_dis((gpio_num_t)nWKUP);
      rtc_gpio_pulldown_dis((gpio_num_t)nWKUP);

      esp_deep_sleep_enable_gpio_wakeup(1ULL << nWKUP, ESP_GPIO_WAKEUP_GPIO_LOW);

      delay(10);

      esp_deep_sleep_start();
    }

    vTaskDelay(pdMS_TO_TICKS(sps_s * 1000));
  }
}

void uploadTask(void *param) {

  while (1) {
    if (!uploadRunning || bootmenuActive) {
      vTaskDelay(pdMS_TO_TICKS(500));
      continue;
    }

    uint16_t endIndex = header.writeIndex;

    LOG_INFO("Start upload cycle\r");
    setLedMode(LED_UPLOAD);

    setupConnect();

    while (header.readIndex != endIndex) {
      mqtt_struct temp;
      readMQTTFromFRAM(FRAM_ADDR_START + header.readIndex * STRUCT_SIZE, temp);
      publishMqttData(system_config.mqtt_topic.c_str(), temp);

      header.readIndex = (header.readIndex + 1) % MAX_RECORDS;
      saveFramHeader();

      mqttClient.loop();
      vTaskDelay(pdMS_TO_TICKS(30));
    }

    LOG_INFO("Transmission complete\r");
    uploadRunning = false;

    WiFi.disconnect(true);
    WiFi.mode(WIFI_OFF);
    mqttClient.disconnect();
  }
}

void runBootmenu() {

  if (!digitalRead(USB_DETECT)) {
    return;
  }

  Serial.println("\nGreetings Professor Falken.\n");

  unsigned long lastPrint = 0;
  uint8_t secondsLeft = 10;

  while (secondsLeft > 0) {

    if (millis() - lastPrint >= 1000) {
      lastPrint = millis();
      Serial.printf("Starting in %u seconds... (press SPACE to enter Bootmenu)\r", secondsLeft);
      secondsLeft--;
    }

    if (Serial.available() > 0) {
      char c = Serial.read();
      if (c == ' ') {
        Serial.println("\nBootmenu activated!\n");

        LOG_SET_LEVEL(DebugLogLevel::LVL_NONE);
        bootmenu_Main();
        LOG_SET_LEVEL(DebugLogLevel::LVL_INFO);
        return;
      }
    }
  }

  Serial.println("\nNo key pressed → starting main program...\n");
}

void bootmenuTask(void *param) {
  for (;;) {
    vTaskDelay(pdMS_TO_TICKS(10));

    if (Serial.available() > 0) {
      char c = Serial.read();
      if (c == ' ') {
        bootmenuActive = true;
        LOG_INFO("Bootmenu activation key detected\r");
        LOG_SET_LEVEL(DebugLogLevel::LVL_NONE);
        bootmenu_Main();
        LOG_SET_LEVEL(DebugLogLevel::LVL_INFO);
        bootmenuActive = false;
      }
    }
  }
}

void crashHandler() {
  while (1) {};
}

void scanI2CBus() {
  LOG_INFO("Scanning I2C bus...\r");

  byte error;
  int nDevices = 0;
  for (byte address = 1; address < 127; address++) {
    Wire.beginTransmission(address);
    error = Wire.endTransmission();
    if (error == 0) {
      LOG_INFO("I2C device found at address 0x", address, "\r");
      nDevices++;
    } else if (error == 4) {
      LOG_ERROR("Unknown error at address 0x", address, "\r");
    }
  }
  if (nDevices == 0) {
    LOG_ERROR("No I2C devices found\r");
  } else {
    LOG_INFO("Scan done\r");
  }
}
//---------------------------------------------



//---------------------------------------------
// MQTT
//---------------------------------------------
void initMQTT() {
  LOG_INFO("Initilize MQTT\r");

  LOG_INFO("MQTT ID: " + system_config.mqtt_id, "\r");
  LOG_INFO("MQTT User: " + system_config.mqtt_user, "\r");
  LOG_INFO("MQTT Pass: " + maskPassword(system_config.mqtt_user_pass), "\r");
  LOG_INFO("MQTT IP/Host: " + system_config.mqtt_server_ip, "\r");
  LOG_INFO("MQTT Port: ", system_config.mqtt_server_port, "\r");
  LOG_INFO("MQTT Topic: ", system_config.mqtt_topic, "\r");

  mqttClient.begin(system_config.mqtt_server_ip.c_str(), system_config.mqtt_server_port, net);

  if (!mqttClient.connect(
        system_config.mqtt_id.c_str(),
        system_config.mqtt_user.c_str(),
        system_config.mqtt_user_pass.c_str())) {
    LOG_ERROR("Initilize MQTT failed!\r");
  } else {
    LOG_INFO("MQTT connected successfully!\r");
  }
}

bool publishMqttData(const char *topic, const mqtt_struct &data) {
  if (!mqttClient.connected()) {
    LOG_WARN("MQTT not connected, skipping publish\r");
    return false;
  }

  StaticJsonDocument<256> doc;

  doc["index"] = data.index;
  doc["status"] = data.status;
  doc["timestamp"] = data.timestamp;
  doc["voltage_battery"] = data.voltage_battery;
  doc["internal_temperature"] = data.internal_temperature;
  doc["internal_offset"] = data.internal_offset;

  for (int i = 0; i < 4; i++) {
    doc["EXT_CH" + String(i + 1)] = data.ext_ch[i];
    doc["EXT_CH" + String(i + 1) + "_Offset"] = data.ext_offset[i];
  }

  String logMsg = "Send dataset #" + String(data.index) + " | Timestamp: " + String(data.timestamp) + " | Bat: " + String(data.voltage_battery / 1000.0, 2) + " V" + " | IntTemp: " + String(data.internal_temperature, 2) + " °C" + " | Offset: " + String(data.internal_offset, 2) + " °C";
  for (int i = 0; i < 4; i++) {
    logMsg += " | CH" + String(i + 1) + ": " + String(data.ext_ch[i], 2) + " °C (Offset: " + String(data.ext_offset[i], 2) + ")";
  }
  LOG_INFO(logMsg.c_str(), "\r");

  String payloadStr;
  serializeJson(doc, payloadStr);

  for (int attempt = 1; attempt <= 3; attempt++) {
    if (mqttClient.publish(topic, payloadStr.c_str(), 1, false)) {
      LOG_INFO("MQTT publish success on attempt ", attempt, "\r");
      return true;
    }
    vTaskDelay(200 / portTICK_PERIOD_MS);
    mqttClient.loop();
  }

  LOG_ERROR("MQTT publish failed after retries\r");
  return false;
}
//---------------------------------------------



//---------------------------------------------
// Internal ADC
//---------------------------------------------
float adc_read_voltage() {
  const int SAMPLES = 5;
  float readings[SAMPLES];

  for (int i = 0; i < SAMPLES; i++) {
    readings[i] = analogRead(VBAT_ADC) * 1.4311f;
    vTaskDelay(pdMS_TO_TICKS(2));
  }

  std::sort(readings, readings + SAMPLES);
  float voltage = readings[SAMPLES / 2];

  LOG_INFO("BAT ADC median=", String(voltage, 2), " mV\r");

  return voltage;
}

float filteredBattery() {
  const int MAX_RETRIES = 5;
  const float MAX_DELTA = 0.15f;
  const float MIN_VOLT = 0.0f;
  const float MAX_VOLT = 5000.0f;

  float best = NAN;

  for (int i = 0; i < MAX_RETRIES; i++) {
    float v = adc_read_voltage();

    LOG_INFO("BAT sample ", String(i), ": ", String(v, 3), " mV\r");

    if (v > MIN_VOLT && v < MAX_VOLT) {
      if (!isnan(lastValidBattery)) {
        float delta = fabs(v - lastValidBattery);

        if (delta > MAX_DELTA) {
          LOG_WARN("BAT outlier detected: Δ=", String(delta, 3),
                   " mV → retry\r");
          vTaskDelay(pdMS_TO_TICKS(5));
          continue;
        }
      }

      best = v;
      break;
    }

    LOG_WARN("BAT invalid sample → retry\r");
    vTaskDelay(pdMS_TO_TICKS(5));
  }

  if (isnan(best)) {
    LOG_ERROR("BAT no valid sample; using lastValidBattery\r");
    if (!isnan(lastValidBattery)) return lastValidBattery;
    return NAN;
  }

  if (!isnan(lastValidBattery)) {
    float alpha = 0.3f;
    float smoothed = lastValidBattery + alpha * (best - lastValidBattery);

    LOG_INFO("BAT smooth: raw=", String(best, 3),
             " → smoothed=", String(smoothed, 3), "\r");

    best = smoothed;
  }

  lastValidBattery = best;

  LOG_INFO("BAT final=", String(best, 3), " mV\r");

  return best;
}
//---------------------------------------------



//---------------------------------------------
// TMP1075
//---------------------------------------------
float tmp_read_temperature(TMP1075::ConversionTime time) {
  float tmp;

  tmp1075.setConversionTime(time);
  tmp = tmp1075.getTemperatureCelsius();
  LOG_INFO("TMP1075: ", String(tmp, 2), " °C\r");
  return tmp;
}
//---------------------------------------------
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

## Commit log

2025-12-02 Intial Commit
    Initial Commit
    [TechBird-SmartSense_Housing_001.FCStd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]
2025-12-03 Changed readme.md
    Added arduino setup
2025-12-06 Added single shot functionality
    Added single shot functionality, which sends directly after a certain time.
    Added check if deepsleep time is at least 10 seconds, as connecting to WiFi and MQTT needs that time.
    Currently it is not timesensitive, soooo the time between points might be bigger as you expect.
    Added used libraries to readme.md
2026-01-09 Update TechBird_SmartSenseOS.ino
    Series Resistor need to be switched to 10k. Will then measure from -35 °C to plus 40 °C or something.
2026-01-10 Update TechBird_SmartSenseOS.ino
    Fixed NTP Stuff
    [TechBird_SmartSenseOS.ino]
2026-01-11 Update TechBird_SmartSenseOS.ino
    Fixed NTP stuff.... hopefully
    [TechBird_SmartSenseOS.ino]
